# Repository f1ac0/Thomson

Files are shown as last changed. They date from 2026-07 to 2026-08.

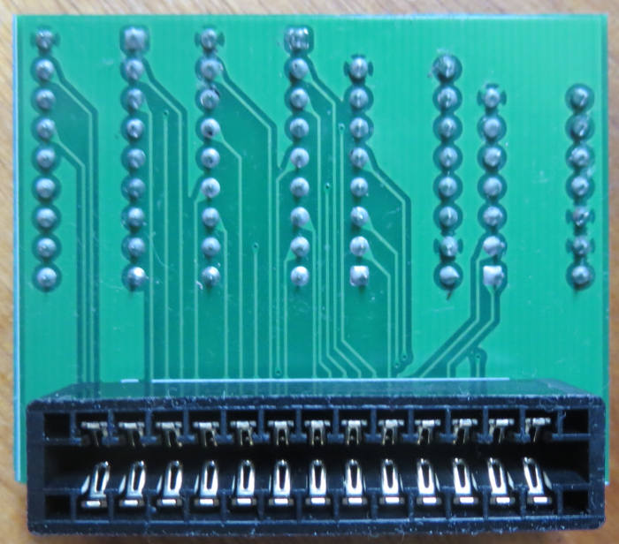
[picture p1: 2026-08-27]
TO7-RAM/Front-FLACO2026.jpg

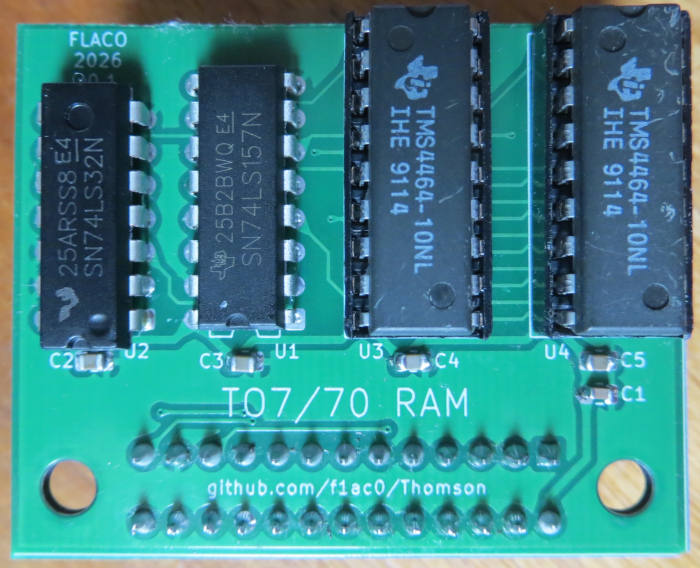
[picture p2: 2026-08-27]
TO7-RAM/Back-FLACO2026.jpg

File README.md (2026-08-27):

# Thomson
Kids in the 80's in France discovered computers at school with the TO and MO series from Thomson.

Interesting expansions exist to enjoy these systems, see below.

In this repository I share the boards I modified for my own needs, for example to use the parts I have in stock, or because I like my own routing.

# Disclaimer and Acknowledgements
This is a hobbyist project, it comes with no warranty and no support. Also remember that the Commodore machines are about 40 years old and may fail because of such hardware expansions.

I publish my work under the CC-BY-NC-SA license, unless stated otherwise. Thanks to everyone who share their knowledge and creations.

# Sources and interesting projects
## Cartridges
- https://dcmoto.pages-perso.free.fr/bricolage/memo7/index.html

## RAM
- https://www.forum.system-cfg.com/viewtopic.php?f=18&t=10807

## Expansions
- https://dcmoto.pages-perso.free.fr/bricolage/sddrive/index.html
- https://dcmoto.pages-perso.free.fr/bricolage/sx90-2018/index.html

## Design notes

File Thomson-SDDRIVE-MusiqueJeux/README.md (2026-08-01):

# Thomson-SDDRIVE-MusiqueJeu
This is an expansion combining the SX90-018 "Contrôleur d'extensions modèle 2" that provides a 6 bit DAC for sound and two DB9 joystick ports and the SDDRIVE that emulates a floppy disk controller. The logic is integrated inside a XC9572XL CPLD and using SMD components to reduce size.

Warning : the two joystick ports use an "Atari" pinout and not the specific thomson-only pinout of the original expansion. Make sure to use standard controllers and not Thomson ones if you own any (I dont). 5V is present so you may use powered controllers, but make sure to use limited power to preserve your host PSU and motherboard.

# Disclaimer and Acknowledgements
This is a hobbyist project, it comes with no warranty and no support. Also remember that the Thomson machines are about 40 years old and may fail because of such hardware expansions.

The author of SDDRIVE keeps the intellectual property of his work and gracefully shares his degigns and agrees that users change, improve and share them, and forbids commercial use and selling the products. the content inside this folder is published under the same licensing terms.

It is not supported by the author of SDDRIVE, please don't bother him with issues you might have with it.

# From original designs by
- SDDRIVE by Daniel Coulom : https://dcmoto.pages-perso.free.fr/bricolage/sddrive/index.html
- SX90-018 by Thomson, schematics reverse engineered by Daniel Coulom for his SX90-2018 : https://dcmoto.pages-perso.free.fr/bricolage/sx90-2018/index.html
Thanks !

# Making it
Components are SMD, and have thin pin pitch. You need to know what you are doing.

Check for shorts at least between 5V, 3.3V, and GND traces before applying power ! I suggest to first install the CPLD and check its connections, then the PLCC socket and also check its connections, before the SD socket and through holes connectors that will maker rework more difficult.

Make sure to apply insulating tape under the SD socket where the contacts from the socket may touch the PCB. In order to keep the two layer PCB, this was not possible to use no copper zone there.

For the edge connector, I used a 2x21=42 pins connecto because I could not find an 2x19 one. If you do so then make sure to remove the four pins on the edges and insert a small piece of PCB to force the connector to be aligned with the PCB edge when inserted.

The ROM is oversized however easily available. You have to program it with the original sddrive_control.bin using an EEPROM programmer. Pad the end of the file up to a size of 524288 or tell your programmer to only burn the lower bytes since the higher addresses are grounded anyway.

Prepare the SDCARD as explained on the SDDRIVE page.

# Using it
Connect it to your Thomson. When the system is starting, it should show the disk drive menu that will start the selector. See the instructions for SDDRIVE, it should behave the same.

# FD2SD
You can use SD files that are compatible with your system. You will find some on the dcmoto website. You can also convert some .FD disk images.

The DCMOTO emulator provides a FD2SD windows tool, if you use a different system you may use the FD2SD in this repo.

Compile it with "gcc -o fd2sd fd2sd.c" then convert a file with "fd2sd file.fd". Check other usage with "fd2sd -h".

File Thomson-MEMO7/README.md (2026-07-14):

# Thomson-MEMO7
A multi-ROM Memo7 for the TO7 computer.
- 32x 16k banks
- 32k and 64k using bank switching
- 3D printed case

# Disclaimer and Acknowledgements
This is a hobbyist project, it comes with no warranty and no support. Also remember that the Commodore machines are about 40 years old and may fail because of such hardware expansions.

I publish my work under the CC-BY-NC-SA license, unless stated otherwise. Thanks to everyone who share their knowledge and creations.

# Inspired by
- https://dcmoto.pages-perso.free.fr/bricolage/memo7/index.html
- https://forum.system-cfg.com/viewtopic.php?f=10&t=7086
- https://www.thingiverse.com/thing:5231941
Thanks !

# Making it
- Install the DIP switch so that the switches are closed when the lever is LOW
- Check for shorts at least between 5V, and GND traces before applying power! Also check that R4 and R5 are not shorted : if they are then the pins of the ROM socket are shorted to the nearby 5V pin and setting A17/A18 switch to LOW will short 5V to ground!

To prepare the ROM image,
- select 16k, 32k and 64k files to fill the 512k ROM chip and decide their order in the ROM,
- for 32k and 64k files, make sure they will start respectively on 32k and 64k boundaries,
- for 4k and 8k file, duplicate them 4 times and 2 times respectively,
- for files that are shorter than 16k, pad them up to the full size,
- concatenate them into one single file,
- burn the file into the EEPROM.

For example on linux : cat 16krom.m7 4krom.m7 4krom.m7 4krom.m7 4krom.m7 32krom.m7 64krom.m7 (...) >romfile

I suggest to print the content of the ROM with the correct switch placement to remember it later:
- LLLLLHH 16krom
- LLLLHHH 4krom
- LLLHHLH 32krom
- LLHHHLL 64krom
- ...

# Using it
Choose the ROM while the system is powered down.
- To select a 16k ROM, dial its address on the A14 to A18 switches. Set the 32k and 64k switches UP.
- To select a 32K ROM, dial its address on the A15 to A18 switches. Set A14 UP and 32k LOW.
- To select a 64K ROM, dial its address on the A16 to A18 switches. Set A14 and A15 UP then 32k and 64k LOW.

Make sure to always set A14 UP when 32K is LOW, and A15 UP when 64k is LOW: failing to do so and setting them LOW at the same time will short to ground the outputs of the 74LS173 and may damage them.

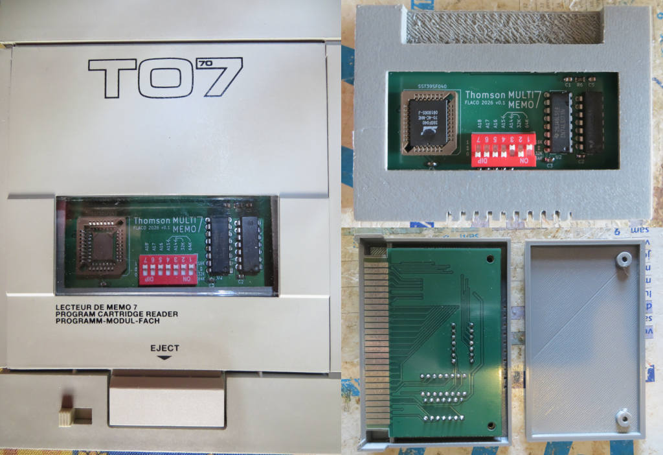
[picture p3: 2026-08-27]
Thomson-MEMO7/MEMO7-FLACO2026.jpg

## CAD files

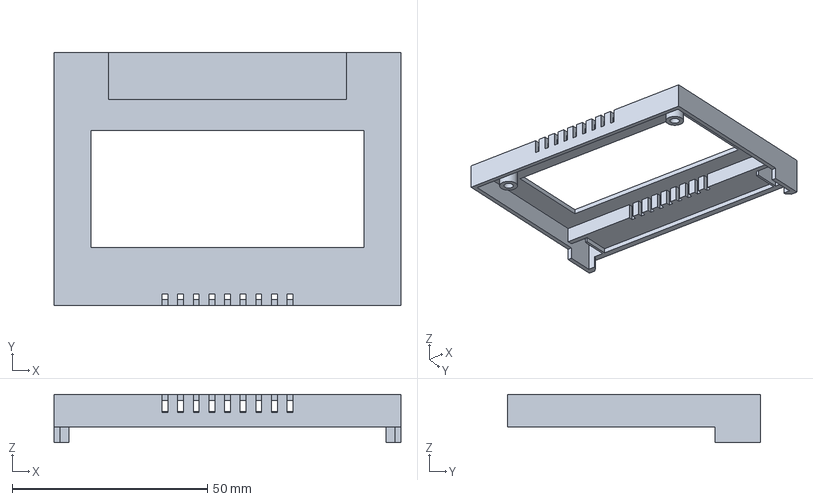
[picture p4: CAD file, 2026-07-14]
Thomson-MEMO7/Case/CaseTop.FCStd
88.9 x 64.8 x 12.3 mm

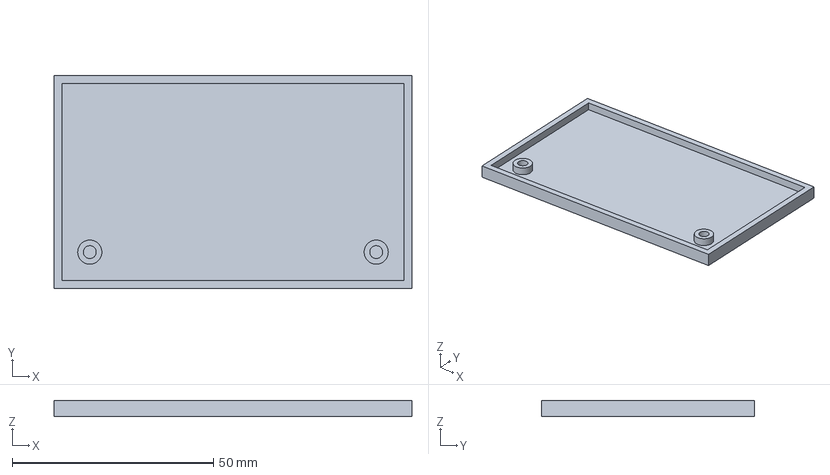
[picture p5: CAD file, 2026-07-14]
Thomson-MEMO7/Case/CaseBot.FCStd
88.9 x 53.0 x 4.00 mm

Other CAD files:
Thomson-MEMO7/Case/CaseBot.stl
Thomson-MEMO7/Case/CaseTop.stl

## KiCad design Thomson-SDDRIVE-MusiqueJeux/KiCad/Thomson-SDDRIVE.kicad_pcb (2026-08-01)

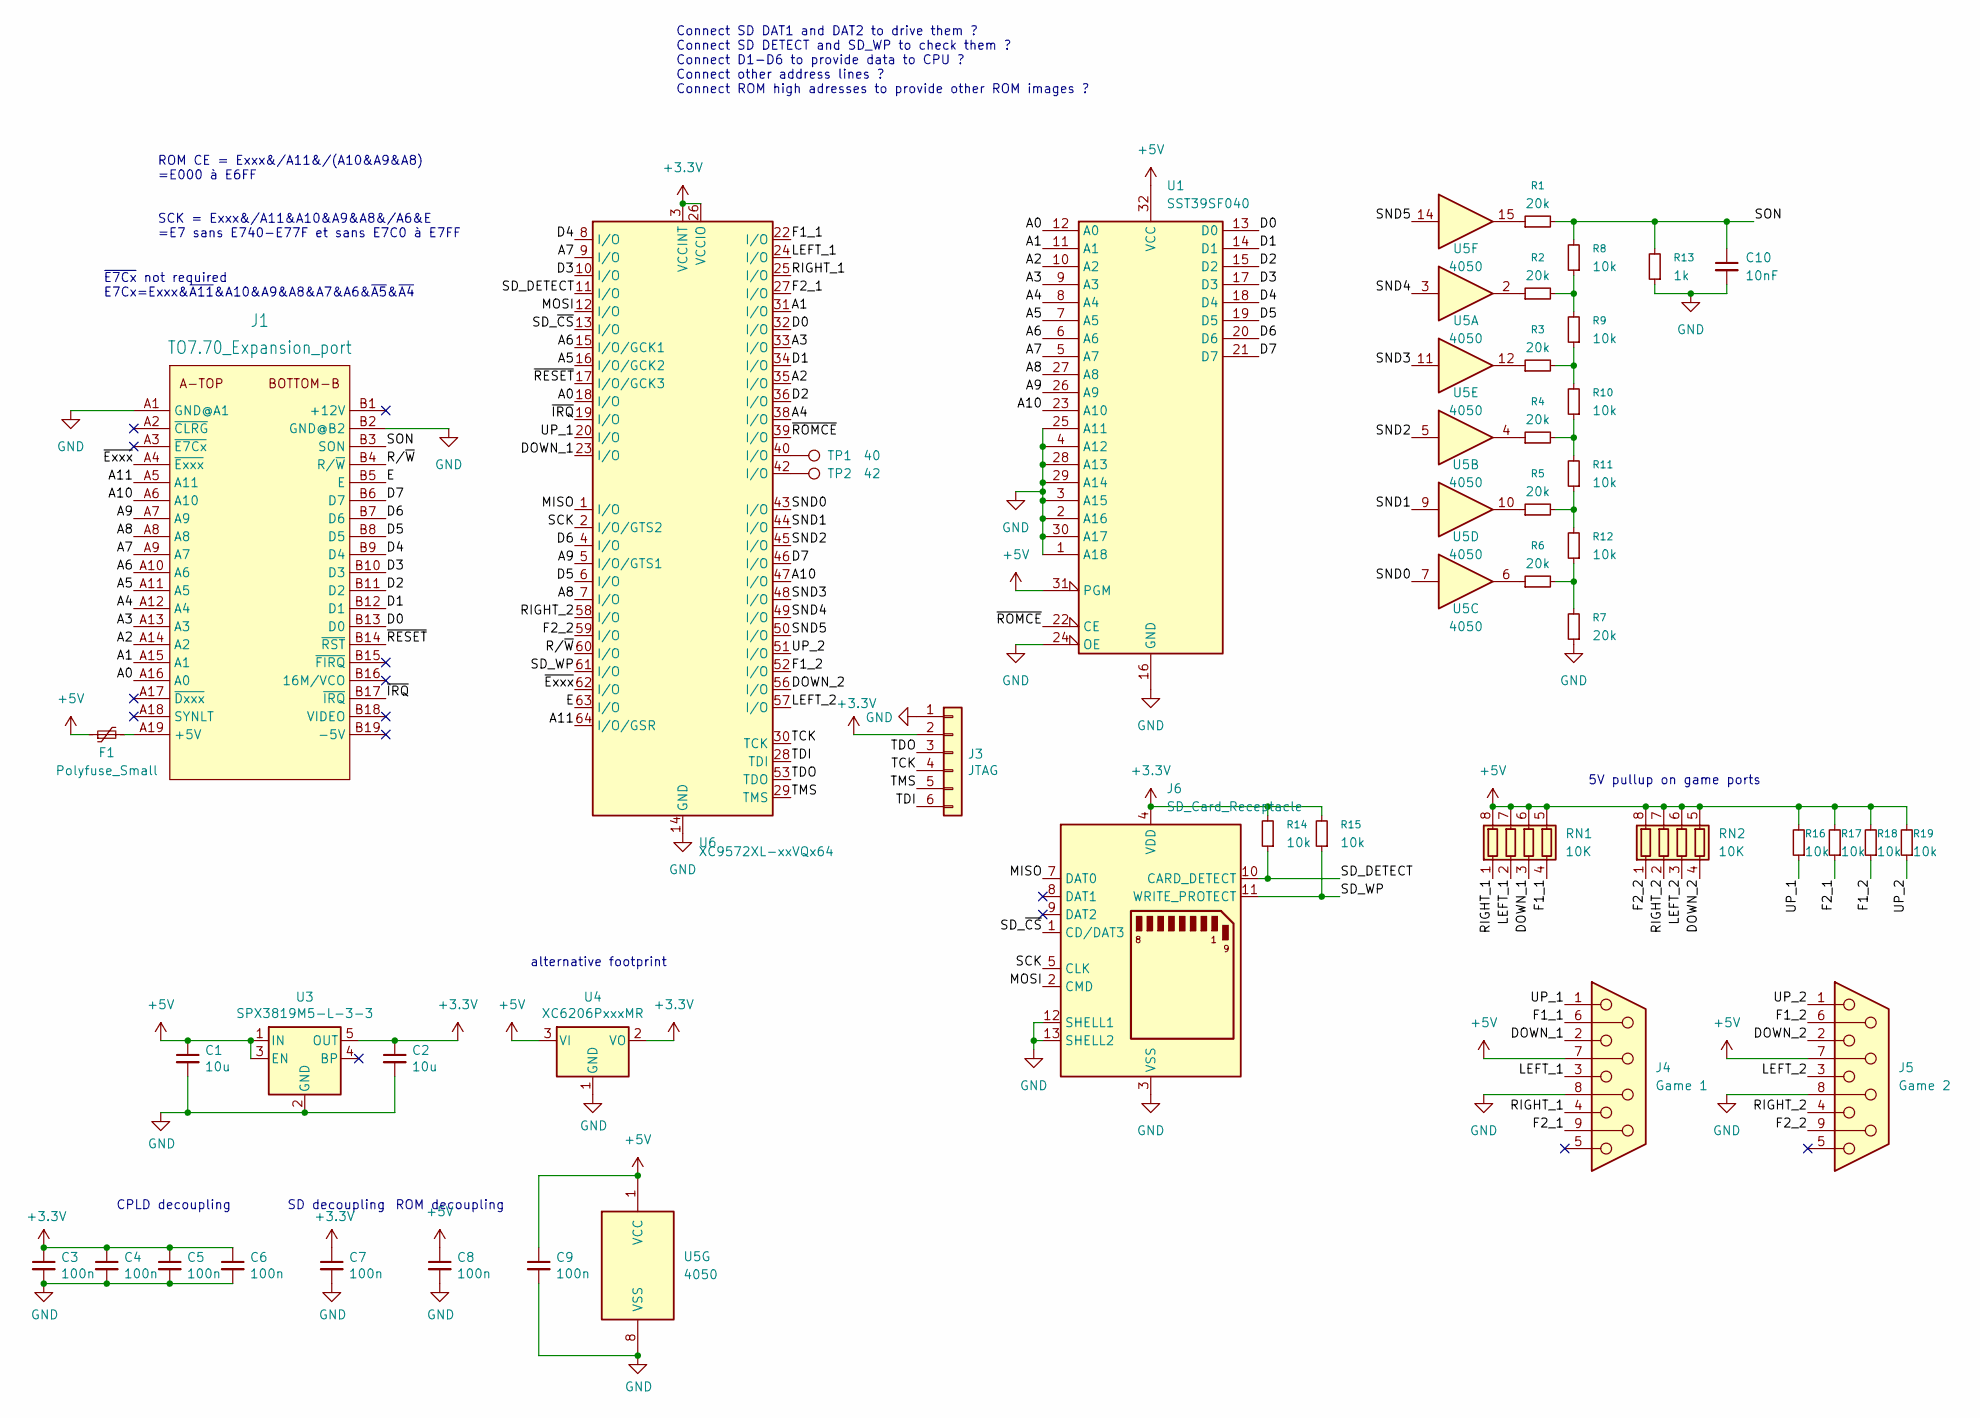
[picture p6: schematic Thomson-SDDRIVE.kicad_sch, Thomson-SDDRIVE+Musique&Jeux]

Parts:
C1, C2: 10u; C_0805_2012Metric
C3, C4, C5, C6, C7, C8, C9: 100n; C_0805_2012Metric
C10: 10nF; C_0805_2012Metric
F1: Polyfuse_Small; R_1210_3225Metric
J1: TO7.70_Expansion_port; TO7.70_Expansion_port_Minibus_3x19_P2.54mm_W5.08mm_Vertical
J3: JTAG; PinHeader_1x06_P2.54mm_Vertical
J4: Game 1; DSUB-9_Pins_Vertical_P2.77x2.84mm
J5: Game 2; DSUB-9_Pins_Vertical_P2.77x2.84mm
J6: SD_Card_Receptacle; Conn_SDcard_largerpads
R1, R2, R3, R4, R5, R6, R7: 20k; R_0805_2012Metric
R8, R9, R10, R11, R12, R14, R15, R16, R17, R18, R19: 10k; R_0805_2012Metric
R13: 1k; R_0805_2012Metric
RN1, RN2: 10K; R_Array_Convex_4x0603
TP1: 40; Measurement_Point_Round-SMD-Pad_VerySmall
TP2: 42; Measurement_Point_Round-SMD-Pad_VerySmall
U1: SST39SF040; PLCC-32_SMD-Socket
U3: SPX3819M5-L-3-3; SOT-23-5
U4: XC6206PxxxMR; SOT-23
U5: 4050; SOIC-16_3.9x9.9mm_P1.27mm
U6: XC9572XL-xxVQx64; TQFP-64_10x10mm_P0.5mm

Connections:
+3.3V: C2.1, C3.1, C4.1, C5.1, C6.1, C7.1, J3.2, J6.4 (VDD), R14.2, R15.2, U3.5 (OUT), U4.2 (VO), U6.3 (VCCINT), U6.26 (VCCIO), U6.37 (VCCINT), U6.55 (VCCIO)
+5V: C1.1, C8.1, C9.1, F1.1, J4.7, J5.7, R16.2, R17.2, R18.2, R19.2, RN1.5 (R4.2), RN1.6 (R3.2), RN1.7 (R2.2), RN1.8 (R1.2), RN2.5 (R4.2), RN2.6 (R3.2), RN2.7 (R2.2), RN2.8 (R1.2), U1.31 (PGM), U1.32 (VCC), U3.1 (IN), U3.3 (EN), U4.3 (VI), U5.1 (VCC)
/A0: J1.A16 (A0), U1.12 (A0), U6.18 (I/O)
/A1: J1.A15 (A1), U1.11 (A1), U6.31 (I/O)
/A2: J1.A14 (A2), U1.10 (A2), U6.35 (I/O)
/A3: J1.A13 (A3), U1.9 (A3), U6.33 (I/O)
/A4: J1.A12 (A4), U1.8 (A4), U6.38 (I/O)
/A5: J1.A11 (A5), U1.7 (A5), U6.16 (I/O/GCK2)
/A6: J1.A10 (A6), U1.6 (A6), U6.15 (I/O/GCK1)
/A7: J1.A9 (A7), U1.5 (A7), U6.9 (I/O)
/A8: J1.A8, U1.27 (A8), U6.7 (I/O)
/A9: J1.A7 (A9), U1.26 (A9), U6.5 (I/O/GTS1)
/A10: J1.A6 (A10), U1.23 (A10), U6.47 (I/O)
/A11: J1.A5 (A11), U6.64 (I/O/GSR)
/D0: J1.B13 (D0), U1.13 (D0), U6.32 (I/O)
/D1: J1.B12 (D1), U1.14 (D1), U6.34 (I/O)
/D2: J1.B11 (D2), U1.15 (D2), U6.36 (I/O)
/D3: J1.B10 (D3), U1.17 (D3), U6.10 (I/O)
/D4: J1.B9 (D4), U1.18 (D4), U6.8 (I/O)
/D5: J1.B8 (D5), U1.19 (D5), U6.6 (I/O)
/D6: J1.B7 (D6), U1.20 (D6), U6.4 (I/O)
/D7: J1.B6 (D7), U1.21 (D7), U6.46 (I/O)
/DOWN_1: J4.2, RN1.3 (R3.1), U6.23 (I/O)
/DOWN_2: J5.2, RN2.4 (R4.1), U6.56 (I/O)
/E: J1.B5 (E), U6.63 (I/O)
/F1_1: J4.6, RN1.4 (R4.1), U6.22 (I/O)
/F1_2: J5.6, R18.1, U6.52 (I/O)
/F2_1: J4.9, R17.1, U6.27 (I/O)
/F2_2: J5.9, RN2.1 (R1.1), U6.59 (I/O)
/LEFT_1: J4.3, RN1.2 (R2.1), U6.24 (I/O)
/LEFT_2: J5.3, RN2.3 (R3.1), U6.57 (I/O)
/MISO: J6.7 (DAT0), U6.1 (I/O)
/MOSI: J6.2 (CMD), U6.12 (I/O)
/RIGHT_1: J4.4, RN1.1 (R1.1), U6.25 (I/O)
/RIGHT_2: J5.4, RN2.2 (R2.1), U6.58 (I/O)
/R/~W: J1.B4 (R/~W), U6.60 (I/O)
/SCK: J6.5 (CLK), U6.2 (I/O/GTS2)
/SD_DETECT: J6.10 (CARD_DETECT), R14.1, U6.11 (I/O)
/SD_WP: J6.11 (WRITE_PROTECT), R15.1, U6.61 (I/O)
/SD_~CS: J6.1 (CD/DAT3), U6.13 (I/O)
/SND0: U5.7, U6.43 (I/O)
/SND1: U5.9, U6.44 (I/O)
/SND2: U5.5, U6.45 (I/O)
/SND3: U5.11, U6.48 (I/O)
/SND4: U5.3, U6.49 (I/O)
/SND5: U5.14, U6.50 (I/O)
/SON: C10.1, J1.B3 (SON), R1.2, R8.2, R13.2
/TCK: J3.4, U6.30 (TCK)
/TDI: J3.6, U6.28 (TDI)
/TDO: J3.3, U6.53 (TDO)
/TMS: J3.5, U6.29 (TMS)
/UP_1: J4.1, R16.1, U6.20 (I/O)
/UP_2: J5.1, R19.1, U6.51 (I/O)
/~Exxx: J1.A4 (~Exxx), U6.62 (I/O)
/~IRQ: J1.B17 (~IRQ), U6.19 (I/O)
/~RESET: J1.B14 (~RST), U6.17 (I/O/GCK3)
/~ROMCE: U1.22 (CE), U6.39 (I/O)
GND: C1.2, C2.2, C3.2, C4.2, C5.2, C6.2, C7.2, C8.2, C9.2, C10.2, J1.A1 (GND@A1), J1.B2 (GND@B2), J3.1, J4.8, J5.8, J6.3 (VSS), J6.6 (VSS), J6.12 (SHELL1), J6.13 (SHELL2), R7.1, R13.1, U1.1 (A18), U1.2 (A16), U1.3 (A15), U1.4 (A12), U1.16 (GND), U1.24 (OE), U1.25 (A11), U1.28 (A13), U1.29 (A14), U1.30 (A17), U3.2 (GND), U4.1 (GND), U5.8 (VSS), U6.14 (GND), U6.21 (GND), U6.41 (GND), U6.54 (GND)
unnamed: F1.2, J1.A19 (+5V)
unnamed: R1.1, U5.15
unnamed: R2.1, U5.2
unnamed: R2.2, R8.1, R9.2
unnamed: R3.1, U5.12
unnamed: R4.1, U5.4
unnamed: R5.1, U5.10
unnamed: R6.1, U5.6
unnamed: R4.2, R10.1, R11.2
unnamed: R3.2, R9.1, R10.2
unnamed: R5.2, R11.1, R12.2
unnamed: R6.2, R7.2, R12.1
unnamed: TP1.1, U6.40 (I/O)
unnamed: TP2.1, U6.42 (I/O)

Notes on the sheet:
~{E7Cx} not required E7Cx=Exxx&~{A11}&A10&A9&A8&A7&A6&~{A5}&~{A4}
5V pullup on game ports
SD decoupling
ROM CE = Exxx&/A11&/(A10&A9&A8) =E000 à E6FF SCK = Exxx&/A11&A10&A9&A8&/A6&E =E7 sans E740-E77F et sans E7C0 à E7FF
alternative footprint
CPLD decoupling
Connect SD DAT1 and DAT2 to drive them ? Connect SD DETECT and SD_WP to check them ? Connect D1-D6 to provide data to CPU ? Connect other address lines ? Connect ROM high adresses to provide other ROM images ?
ROM decoupling

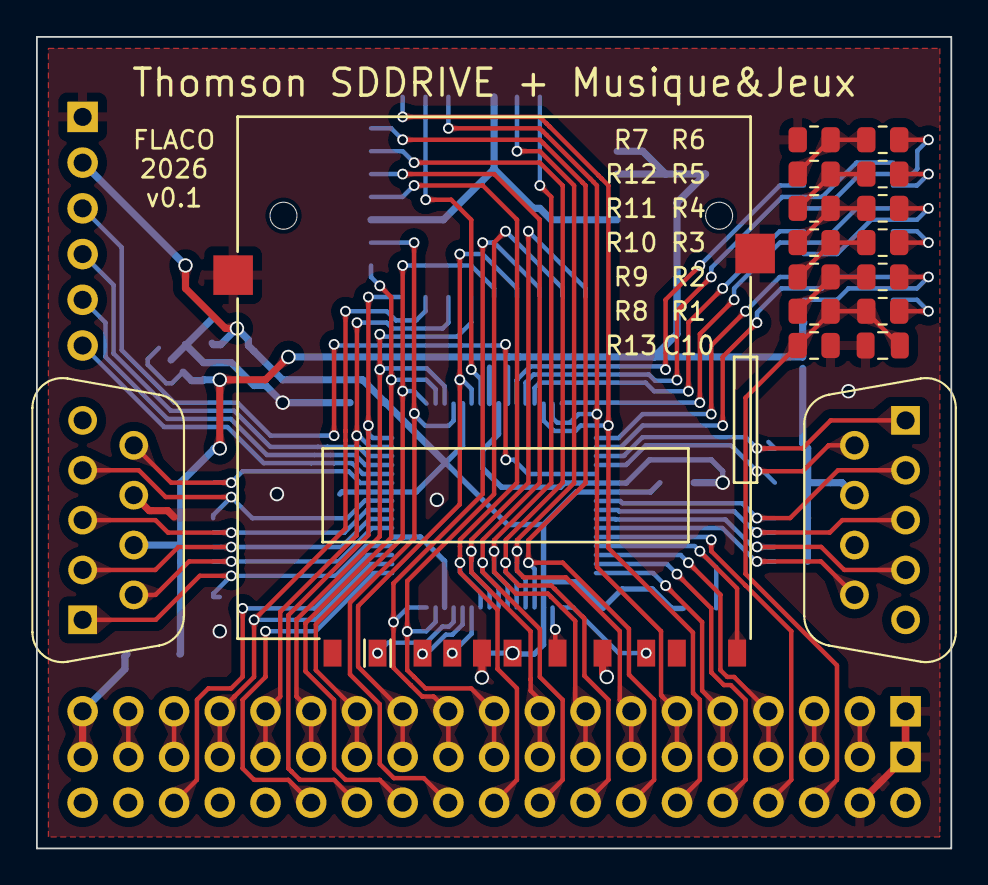
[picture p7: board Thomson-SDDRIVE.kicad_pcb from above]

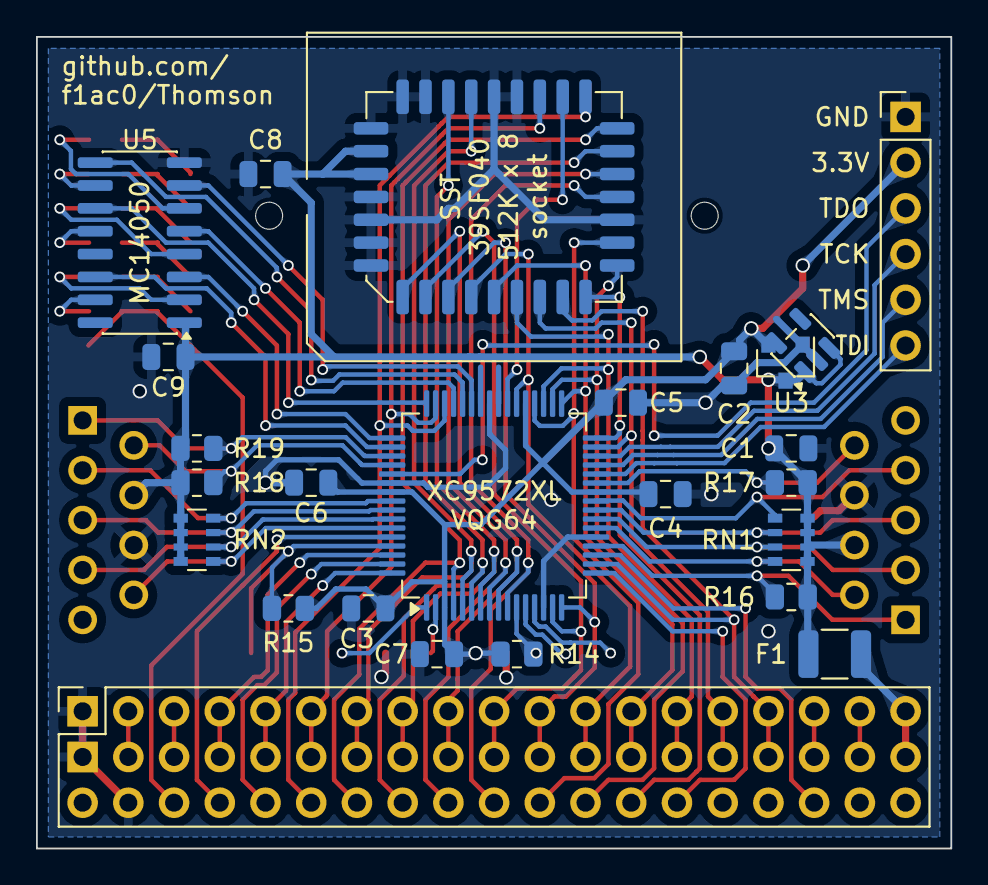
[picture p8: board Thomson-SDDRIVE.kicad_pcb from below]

Board: 2 copper layers, 50.8 x 45.1 mm, 42 parts (25 on the bottom side), 70 nets.

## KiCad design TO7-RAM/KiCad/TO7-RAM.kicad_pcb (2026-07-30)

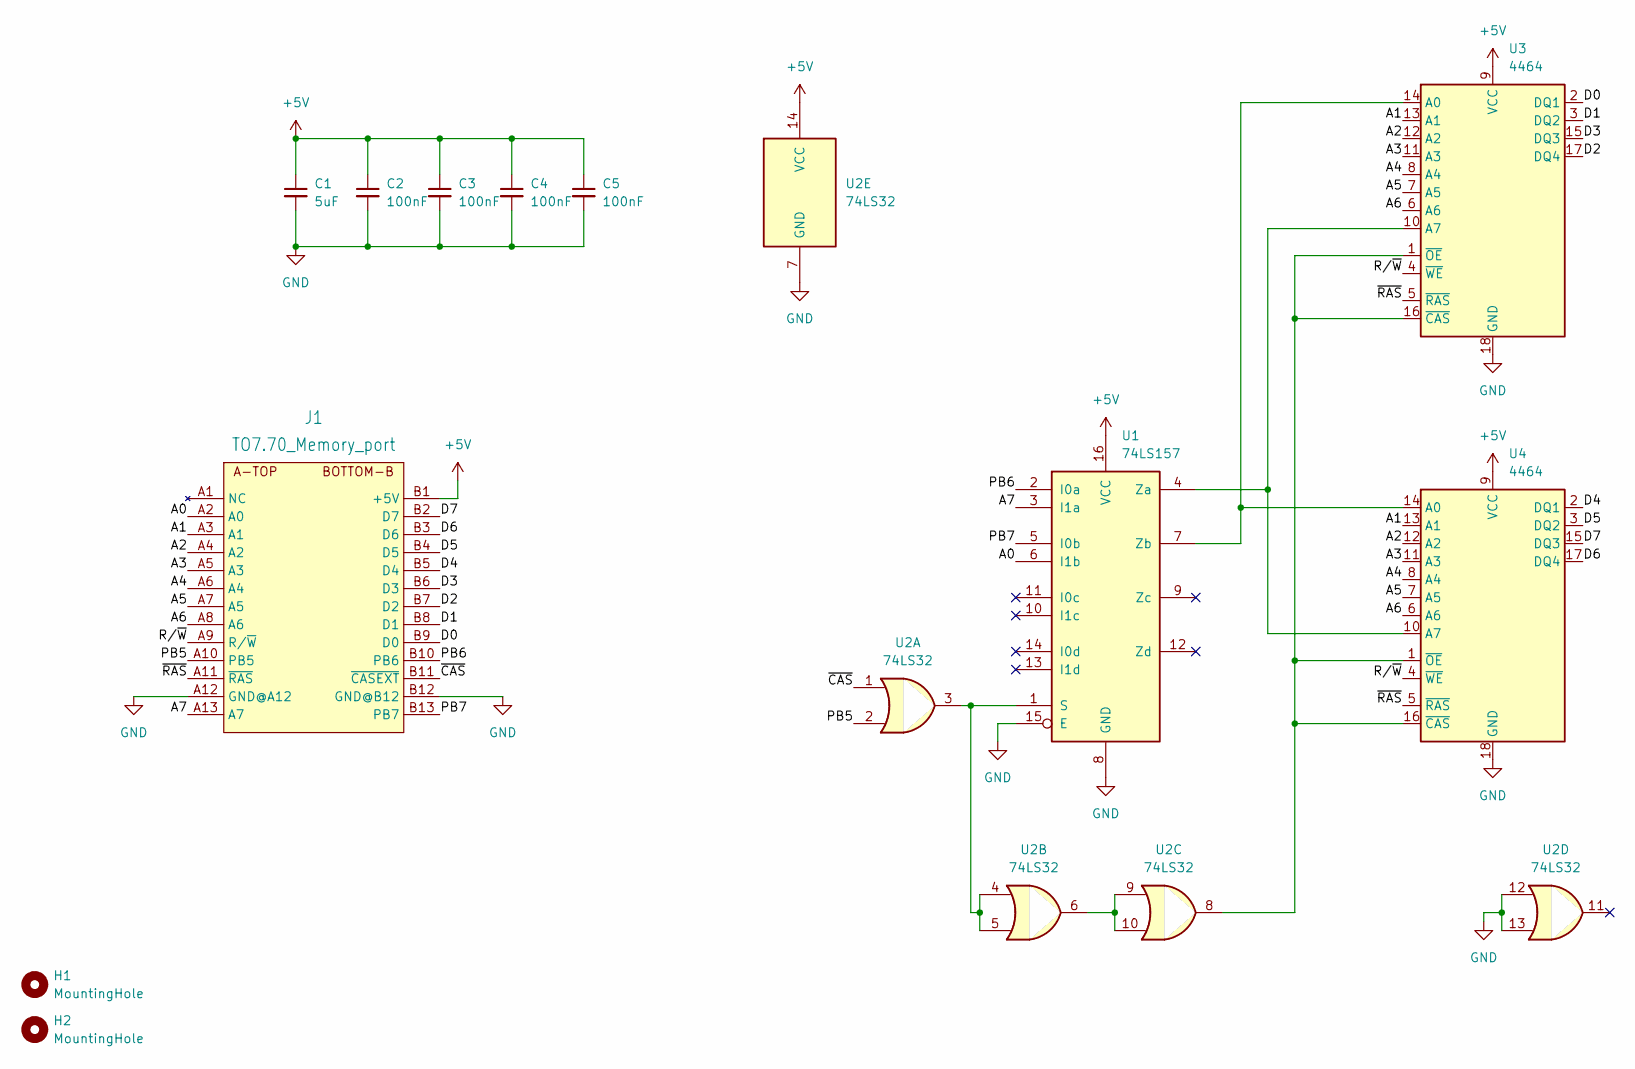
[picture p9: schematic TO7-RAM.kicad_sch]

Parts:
C1: 5uF; C_0805_2012Metric
C2, C3, C4, C5: 100nF; C_0805_2012Metric
H1, H2: MountingHole; MountingHole_4mm
J1: TO7.70_Memory_port; TO7.70_Memory_port_2x13_P2.54mm_W5.08mm_Vertical
U1: 74LS157; DIP-16_W7.62mm
U2: 74LS32; DIP-14_W7.62mm
U3, U4: 4464; DIP-18_W7.62mm_Socket

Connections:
+5V: C1.1, C2.1, C3.1, C4.1, C5.1, J1.B1 (+5V), U1.16 (VCC), U2.14 (VCC), U3.9 (VCC), U4.9 (VCC)
/A0: J1.A2 (A0), U1.6 (I1b)
/A1: J1.A3 (A1), U3.13 (A1), U4.13 (A1)
/A2: J1.A4 (A2), U3.12 (A2), U4.12 (A2)
/A3: J1.A5 (A3), U3.11 (A3), U4.11 (A3)
/A4: J1.A6 (A4), U3.8 (A4), U4.8 (A4)
/A5: J1.A7 (A5), U3.7 (A5), U4.7 (A5)
/A6: J1.A8 (A6), U3.6 (A6), U4.6 (A6)
/A7: J1.A13 (A7), U1.3 (I1a)
/D0: J1.B9 (D0), U3.2 (DQ1)
/D1: J1.B8 (D1), U3.3 (DQ2)
/D2: J1.B7 (D2), U3.17 (DQ4)
/D3: J1.B6 (D3), U3.15 (DQ3)
/D4: J1.B5 (D4), U4.2 (DQ1)
/D5: J1.B4 (D5), U4.3 (DQ2)
/D6: J1.B3 (D6), U4.17 (DQ4)
/D7: J1.B2 (D7), U4.15 (DQ3)
/PB5: J1.A10 (PB5), U2.2
/PB6: J1.B10 (PB6), U1.2 (I0a)
/PB7: J1.B13 (PB7), U1.5 (I0b)
/R/~W: J1.A9 (R/~W), U3.4 (~WE), U4.4 (~WE)
/~CAS: J1.B11 (~CASEXT), U2.1
/~RAS: J1.A11 (~RAS), U3.5 (~RAS), U4.5 (~RAS)
GND: C1.2, C2.2, C3.2, C4.2, C5.2, J1.A12 (GND@A12), J1.B12 (GND@B12), U1.8 (GND), U1.15 (E), U2.7 (GND), U2.12, U2.13, U3.18 (GND), U4.18 (GND)
unnamed: U1.1 (S), U2.3, U2.4, U2.5
unnamed: U1.4 (Za), U3.10 (A7), U4.10 (A7)
unnamed: U1.7 (Zb), U3.14 (A0), U4.14 (A0)
unnamed: U2.6, U2.9, U2.10
unnamed: U2.8, U3.1 (~OE), U3.16 (~CAS), U4.1 (~OE), U4.16 (~CAS)

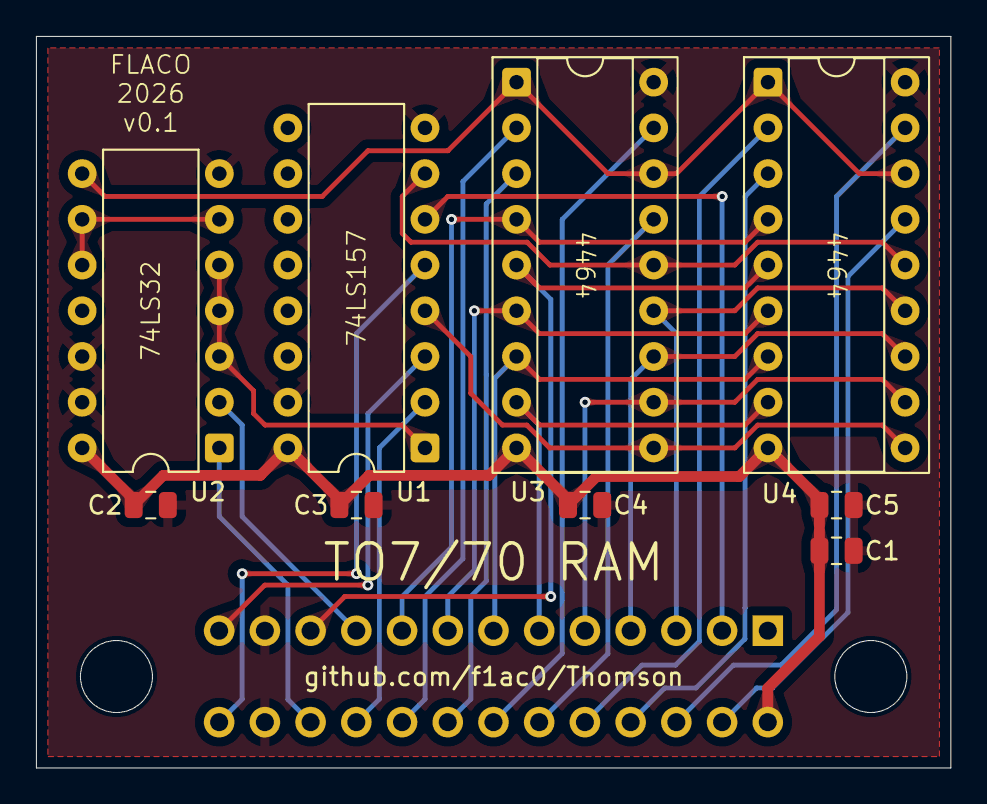
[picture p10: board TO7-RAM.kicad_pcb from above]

Board: 2 copper layers, 50.8 x 40.6 mm, 12 parts (1 on the bottom side), 29 nets.

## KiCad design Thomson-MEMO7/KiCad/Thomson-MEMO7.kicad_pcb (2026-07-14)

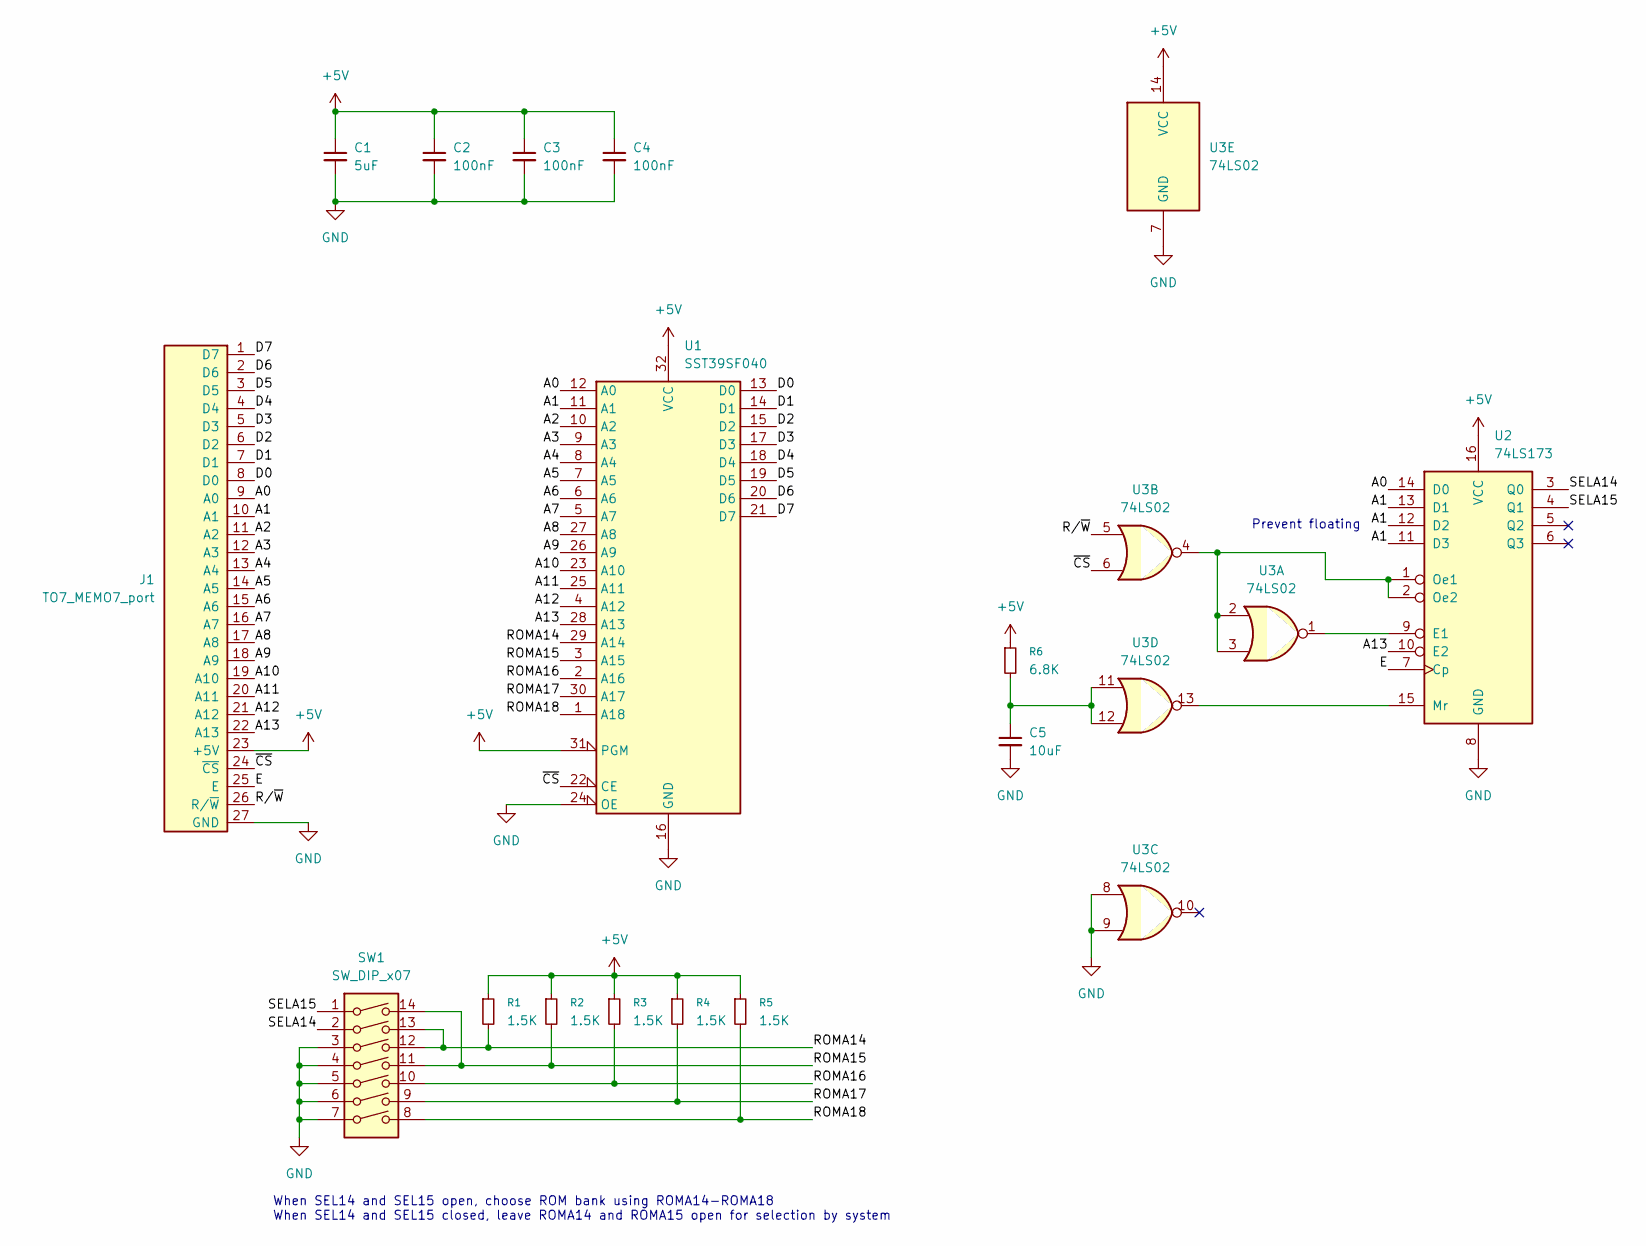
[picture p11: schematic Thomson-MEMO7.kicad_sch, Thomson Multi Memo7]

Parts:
C1: 5uF; C_0805_2012Metric
C2, C3, C4: 100nF; C_0805_2012Metric
C5: 10uF; C_0805_2012Metric
J1: TO7_MEMO7_port; TO7_MEMO7
R1, R2, R3, R4, R5: 1.5K; R_0805_2012Metric
R6: 6.8K; R_0805_2012Metric
SW1: SW_DIP_x07; SW_DIP_SPSTx07_Slide_9.78x19.96mm_W7.62mm_P2.54mm
U1: SST39SF040; PLCC-32_SMD-Socket
U2: 74LS173; DIP-16_W7.62mm
U3: 74LS02; DIP-14_W7.62mm

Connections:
+5V: C1.1, C2.1, C3.1, C4.1, J1.23 (+5V), R1.1, R2.1, R3.1, R4.1, R5.1, R6.1, U1.31 (PGM), U1.32 (VCC), U2.16 (VCC), U3.14 (VCC)
/A0: J1.9 (A0), U1.12 (A0), U2.14 (D0)
/A1: J1.10 (A1), U1.11 (A1), U2.11 (D3), U2.12 (D2), U2.13 (D1)
/A2: J1.11 (A2), U1.10 (A2)
/A3: J1.12 (A3), U1.9 (A3)
/A4: J1.13 (A4), U1.8 (A4)
/A5: J1.14 (A5), U1.7 (A5)
/A6: J1.15 (A6), U1.6 (A6)
/A7: J1.16 (A7), U1.5 (A7)
/A8: J1.17 (A8), U1.27 (A8)
/A9: J1.18 (A9), U1.26 (A9)
/A10: J1.19 (A10), U1.23 (A10)
/A11: J1.20 (A11), U1.25 (A11)
/A12: J1.21 (A12), U1.4 (A12)
/A13: J1.22 (A13), U1.28 (A13), U2.10 (E2)
/D0: J1.8 (D0), U1.13 (D0)
/D1: J1.7 (D1), U1.14 (D1)
/D2: J1.6 (D2), U1.15 (D2)
/D3: J1.5 (D3), U1.17 (D3)
/D4: J1.4 (D4), U1.18 (D4)
/D5: J1.3 (D5), U1.19 (D5)
/D6: J1.2 (D6), U1.20 (D6)
/D7: J1.1 (D7), U1.21 (D7)
/E: J1.25 (E), U2.7 (Cp)
/ROMA14: R1.2, SW1.12, SW1.13, U1.29 (A14)
/ROMA15: R2.2, SW1.11, SW1.14, U1.3 (A15)
/ROMA16: R3.2, SW1.10, U1.2 (A16)
/ROMA17: R4.2, SW1.9, U1.30 (A17)
/ROMA18: R5.2, SW1.8, U1.1 (A18)
/R/~W: J1.26 (R/~W), U3.5
/SELA14: SW1.2, U2.3 (Q0)
/SELA15: SW1.1, U2.4 (Q1)
/~CS: J1.24 (~CS), U1.22 (CE), U3.6
GND: C1.2, C2.2, C3.2, C4.2, C5.2, J1.27 (GND), SW1.3, SW1.4, SW1.5, SW1.6, SW1.7, U1.16 (GND), U1.24 (OE), U2.8 (GND), U3.7 (GND), U3.8, U3.9
unnamed: C5.1, R6.2, U3.11, U3.12
unnamed: U2.9 (E1), U3.1
unnamed: U2.15 (Mr), U3.13
unnamed: U2.1 (Oe1), U2.2 (Oe2), U3.2, U3.3, U3.4

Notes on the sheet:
Prevent floating
When SEL14 and SEL15 open, choose ROM bank using ROMA14-ROMA18 When SEL14 and SEL15 closed, leave ROMA14 and ROMA15 open for selection by system

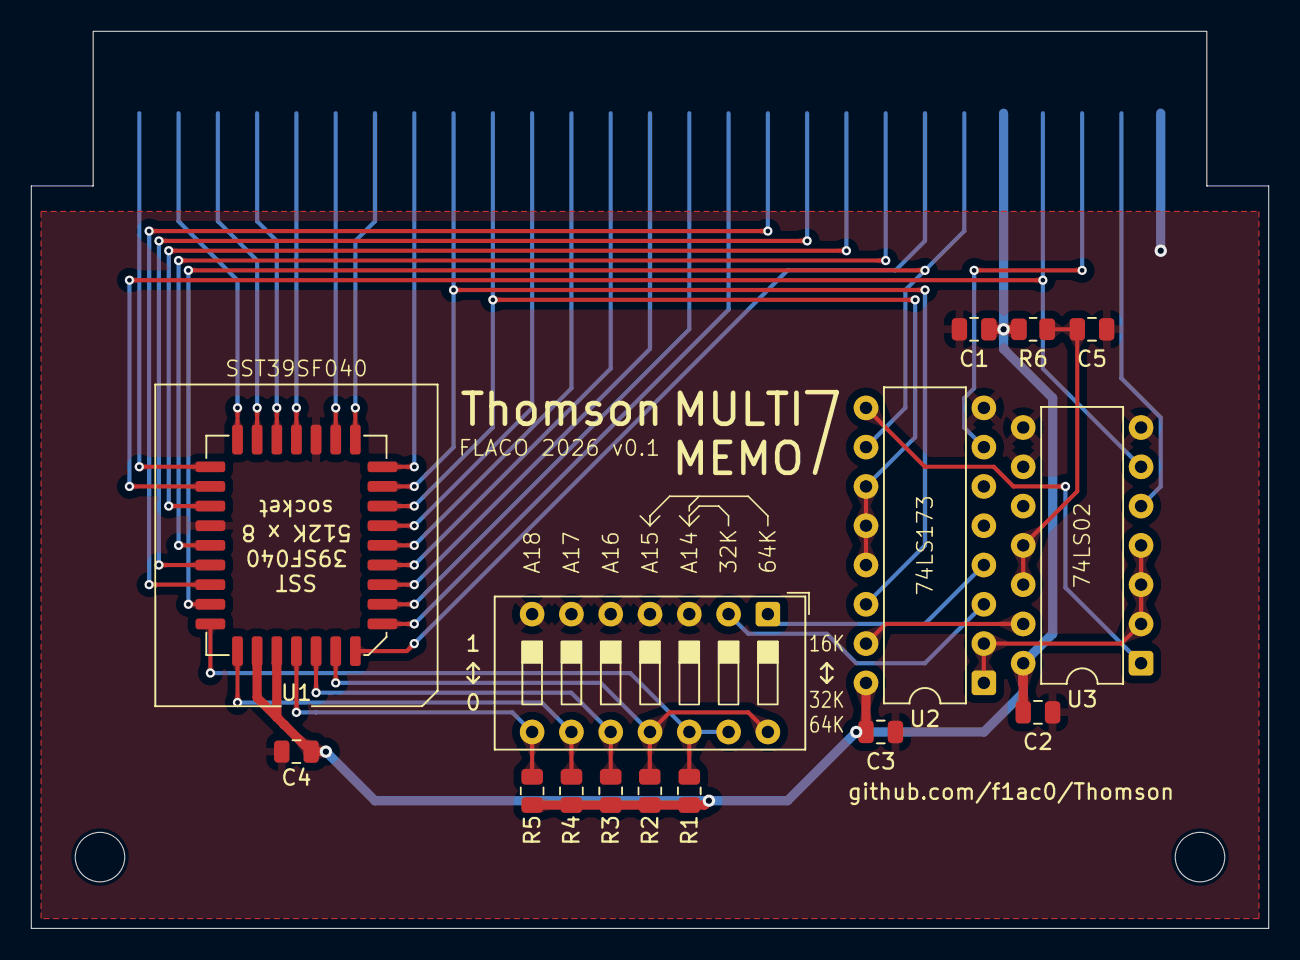
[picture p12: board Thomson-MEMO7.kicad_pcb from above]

Board: 2 copper layers, 80.0 x 58.0 mm, 16 parts (1 on the bottom side), 38 nets.

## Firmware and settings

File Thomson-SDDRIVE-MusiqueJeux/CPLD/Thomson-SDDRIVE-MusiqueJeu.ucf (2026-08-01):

PIN "E"	LOC = P63;
PIN "RW"	LOC = P60;
PIN "D<0>"	LOC = P32;
PIN "D<1>"	LOC = P34;
PIN "D<2>"	LOC = P36;
PIN "D<3>"	LOC = P10;
PIN "D<4>"	LOC = P8;
PIN "D<5>"	LOC = P6;
PIN "D<6>"	LOC = P4;
PIN "D<7>"	LOC = P46;
PIN "_CSE"	LOC = P62;
PIN "A<0>"	LOC = P18;
PIN "A<1>"	LOC = P31;
PIN "A<2>"	LOC = P35;
PIN "A<3>"	LOC = P33;
PIN "A<4>"	LOC = P38;
PIN "A<5>"	LOC = P16;
PIN "A<6>"	LOC = P15;
PIN "A<7>"	LOC = P9;
PIN "A<8>"	LOC = P7;
PIN "A<9>"	LOC = P5;
PIN "A<10>"	LOC = P47;
PIN "A<11>"	LOC = P64;
PIN "_IRQ"	LOC = P19;
PIN "_RST"	LOC = P17;
PIN "_ROMCE"	LOC = P39;
PIN "SD_CS"	LOC = P13;
PIN "SD_SCK"	LOC = P2;
PIN "SD_MOSI"	LOC = P12;
PIN "SD_MISO"	LOC = P1;
PIN "SON<0>"	LOC = P43;
PIN "SON<1>"	LOC = P44;
PIN "SON<2>"	LOC = P45;
PIN "SON<3>"	LOC = P48;
PIN "SON<4>"	LOC = P49;
PIN "SON<5>"	LOC = P50;
PIN "J1<0>"	LOC = P20;
PIN "J1<1>"	LOC = P23;
PIN "J1<2>"	LOC = P24;
PIN "J1<3>"	LOC = P25;
PIN "J1<4>"	LOC = P22;
PIN "J1<5>"	LOC = P27;
PIN "J2<0>"	LOC = P51;
PIN "J2<1>"	LOC = P56;
PIN "J2<2>"	LOC = P57;
PIN "J2<3>"	LOC = P58;
PIN "J2<4>"	LOC = P52;
PIN "J2<5>"	LOC = P59;

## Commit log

2026-07-14 Respository init with MEMO7 files, Readme and License
    [CaseBot.FCStd, CaseBot.stl, CaseTop.FCStd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]
2026-07-30 Addition of TO7-RAM files
    [TO7-RAM.kicad_pcb, TO7-RAM.kicad_sch]
2026-08-01 Addition of Thomson-SDDRIVE-MusiqueJeux files
    [Thomson-SDDRIVE.kicad_pcb, Thomson-SDDRIVE.kicad_sch]
2026-08-19 Thomson-SDDRIVE-MusiqueJeux: more complete register selection to allow detection by sddrive selector and more accurate transition detection on interrupt pins to prevent triggering an interrupt that w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

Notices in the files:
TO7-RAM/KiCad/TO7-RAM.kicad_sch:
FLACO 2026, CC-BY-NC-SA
